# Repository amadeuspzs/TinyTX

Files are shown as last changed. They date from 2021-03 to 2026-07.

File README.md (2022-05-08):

# TinyTX

This repo picks up on the work on Nathan Chantrell, sadly R.I.P. late 2020.

* Nathan's website [via Archive.org](https://web.archive.org/web/20150202220320/http://nathan.chantrell.net/tinytx-wireless-sensor/)
* Nathan's [TinyTX repo on Github](https://github.com/nathanchantrell/TinyTX)
* Archive of [TinyTX3 hardware](TinyTX3/)

## Motivation

Since Nathan created TinyTX, both chips have evolved:

1. RFM12B -> [RFM69](https://www.hoperf.com/modules/rf_transceiver/index.html)
2. ATtiny84 -> ATtiny 0,1 series e.g. [ATtiny1614](https://ww1.microchip.com/downloads/en/DeviceDoc/ATtiny1614-16-17-DataSheet-DS40002204A.pdf)

## High level design

This project will create a TinyTX4 using:

1. RFM69HW
2. ATtiny1614
3. lowpowerlab's [RFM69](https://github.com/lowpowerlab/rfm69) library

And release all hardware and software in this repository.

## Radio module choice

Here is a comparison of [RFM69](https://www.hoperf.com/modules/rf_transceiver/index.html) variants:

Variant|Output (dBm)|Pinout|Size (mm)
---|---|---|---
RFM69[**W**](https://www.hoperf.com/modules/rf_transceiver/RFM69W.html)|13|RFM69W|19.7 x 16
RFM69[**CW**](https://www.hoperf.com/modules/rf_transceiver/RFM69C.html)|13|RFM69CW|16 x 16
RFM69[**HW**](https://www.hoperf.com/%20modules/rf_transceiver/RFM69HW.html)|20|RFM69W|19.7 x 16
RFM69[**HCW**](https://www.hoperf.com/modules/rf_transceiver/RFM69HCW.html)|20|RFM69HCW|16 x 16

i.e. RFM69W and RFM69HW share pinout, but are larger (19.7&nbsp;x&nbsp;16)mm vs the RFMCW and RFMHCW (16&nbsp;x&nbsp;16)mm.

For interoperability between normal and high-power modules, we'll go with the **RFM69(H)W** modules.

## Hardware versions

* [TinyTX4](hardware/TinyTX4) (monopole and SMA)

TinyTX4 Gif

## Software

See [software](software/) page.

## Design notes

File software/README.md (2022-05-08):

# TinyTX4 Software

* [Heartbeat (ping) sketch](ping/) - pings your gateway every ~5s
* [Heartbeat (ping-sleep) sketch](ping/) - pings your gateway every ~64s with sleep in between
* [Low power profiling](low-power-test/) - cycles 1s on and off with radio sleep to check power consumption
* [HC-SR04 Ultrasonic distance sensor](HC-SR04) - WIP water level sensor

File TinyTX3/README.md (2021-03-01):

# TinyTX3 Hardware

Archived from Nathan's website [via Archive.org](https://web.archive.org/web/20150202220320/http://nathan.chantrell.net/tinytx-wireless-sensor/):

## Schematic

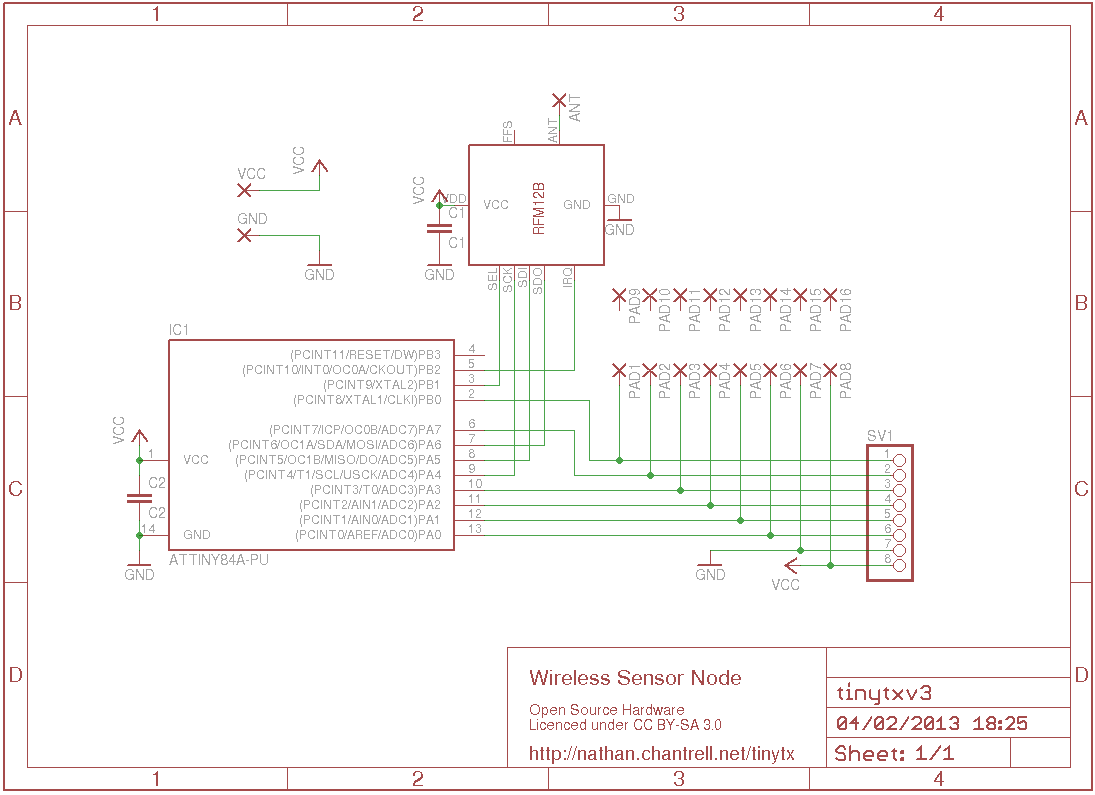
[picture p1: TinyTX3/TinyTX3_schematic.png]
Schematic


* [Eagle file](tinytx3.sch)
* [KiCad files](KiCad/)

## Board

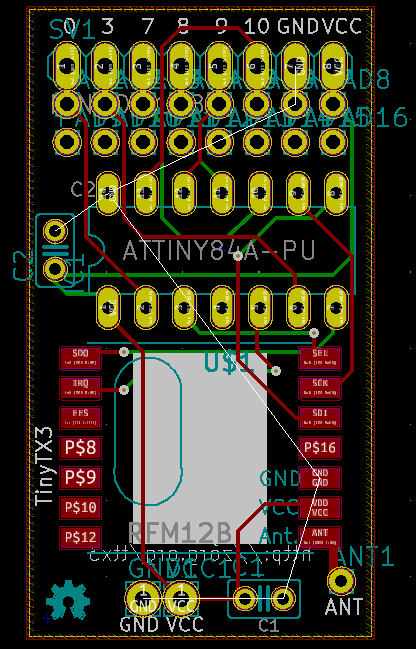
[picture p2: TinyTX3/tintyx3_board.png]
Board


* [Eagle file](tinytx3.brd)
* [KiCad files](KiCad/)

## Case

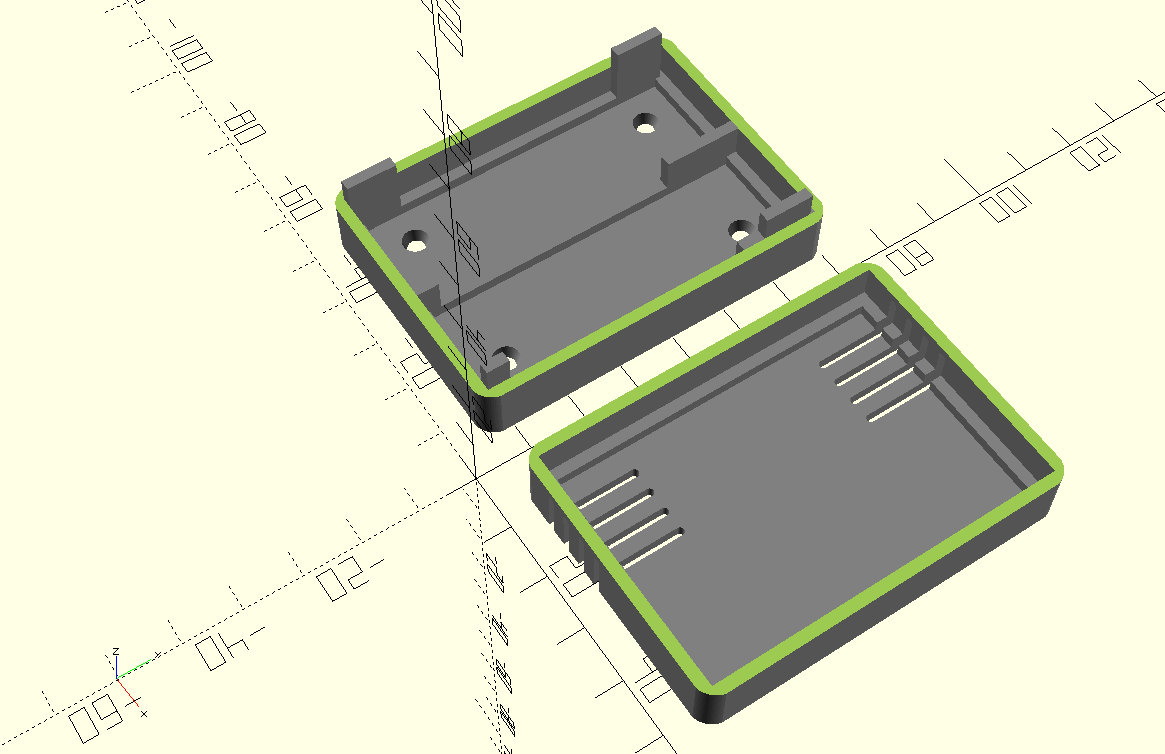
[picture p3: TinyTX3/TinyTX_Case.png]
Case


* [OpenSCAD](TinyTX_Case.scad)

## Implementation

### Pinout

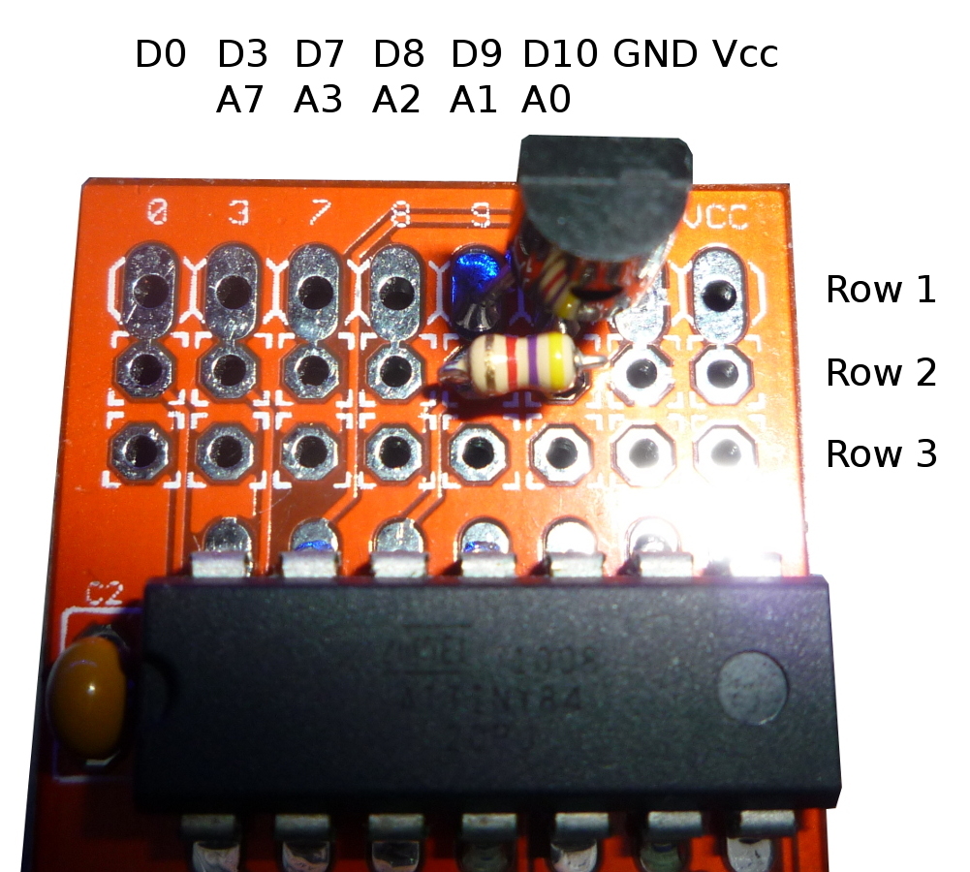
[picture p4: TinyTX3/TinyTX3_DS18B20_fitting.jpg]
Pinout


### AA implementation

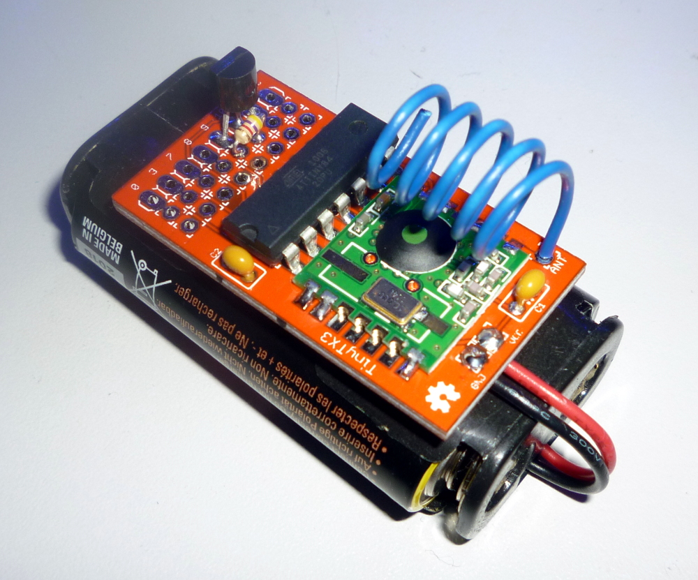
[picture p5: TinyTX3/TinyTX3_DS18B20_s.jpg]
AA implementation


### LiPo implementation

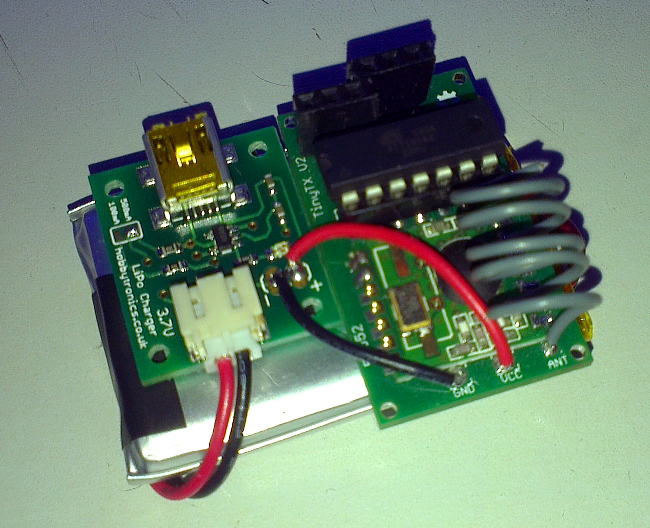
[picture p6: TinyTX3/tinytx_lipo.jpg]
LiPo implementation


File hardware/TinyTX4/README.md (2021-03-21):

# TinyTX4

Upgrades from TinyTX3:

* Updated to RFM69HW/W module
* Updated to ATtiny1614 SOIC
* Added optional [MCP1700](https://ww1.microchip.com/downloads/en/DeviceDoc/22049f.pdf)|[MCP1703](https://ww1.microchip.com/downloads/en/DeviceDoc/22049f.pdf) regulator for ~4-6V~ input ultra low dropout or ~4-16V input range (e.g. 9V battery, Lead Acid cells...). These can be bought in 3.3V or 5V out
* Added programming header with UPDI
* Labelled RX/TX ports for hardware UART
* Added ground planes to improved antenna performance
* Added optional SMA PCB for improved antenna performance

The monopole version keeps the same overall dimensions of TinyTX3.

## Monopole design

TinyTX4 schematic

TinyTX4 PCB front

TinyTX4 PCB rear

## SMA design

TinyTX4_sma PCB front

TinyTX4_sma PCB rear

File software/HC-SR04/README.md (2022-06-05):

# HC-SR04

Low power Ultrasonic range-finder:

1. CS-100 based HC-SR04 (3.3V)
2. NewPing with [modification to support ATTiny1614](https://bitbucket.org/teckel12/arduino-new-ping/pull-requests/8)
3. BSS84 MOSFET to switch on HC-SR04 (inverse), or power directly off GPIO

## Energy usage

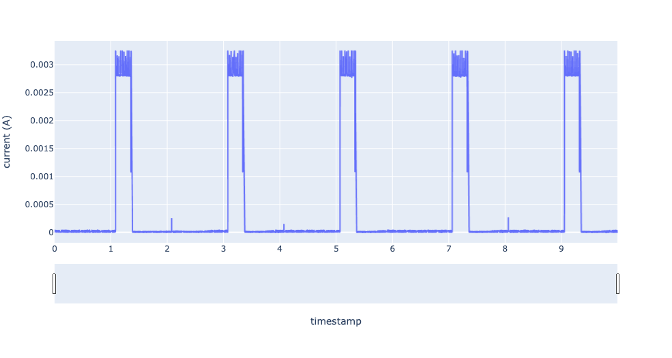
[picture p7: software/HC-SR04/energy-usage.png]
Energy usage diagram


* 20uA background =
* 3mA for ~150ms every 10 mins = 0.45mAs

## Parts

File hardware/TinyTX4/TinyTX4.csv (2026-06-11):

Reference | Qty | Value | DNP | Exclude from BOM | Exclude from Board | Footprint | Datasheet
AE1 | 1 | Antenna |  |  |  | Connector_Wire:SolderWirePad_1x01_Drill1mm | ~
BT1 | 1 | Battery |  |  |  | Connector_Wire:SolderWirePad_1x02_P3.81mm_Drill1mm | ~
C1,C2 | 2 | 0.1uF |  |  |  | Capacitor_SMD:C_1206_3216Metric_Pad1.42x1.75mm_HandSolder | ~
C3,C4 | 2 | 1uF |  |  |  | Capacitor_SMD:C_1206_3216Metric_Pad1.42x1.75mm_HandSolder | ~
J1 | 1 | Conn_01x03_Male |  |  |  | Connector_Wire:SolderWirePad_1x03_P3.175mm_Drill1mm | ~
J2 | 1 | Conn_01x08_Female |  |  |  | kicad-custom:SolderWirePadOval_1x08_Drill1mm | ~
J3,J4 | 2 | Conn_01x08_Female |  |  |  | kicad-custom:SolderWirePad_1x08_Drill1mm | ~
R1,R2 | 2 | R |  |  |  |  | ~
U1 | 1 | ATtiny1614-SS |  |  |  | Package_SO:SOIC-14_3.9x8.7mm_P1.27mm | http://ww1.microchip.com/downloads/en/DeviceDoc/ATtiny1614-data-sheet-40001995A.pdf
U2 | 1 | RFM69HW |  |  |  | RF_Module:HOPERF_RFM69HW | https://www.hoperf.com/data/upload/portal/20181127/5bfcbb56f1fd7.pdf
U3 | 1 | MCP1703A-3302_SOT23 |  |  |  | Package_TO_SOT_SMD:SOT-23 | http://ww1.microchip.com/downloads/en/DeviceDoc/20005122B.pdf

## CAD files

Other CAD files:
TinyTX3/TinyTX_Case.scad

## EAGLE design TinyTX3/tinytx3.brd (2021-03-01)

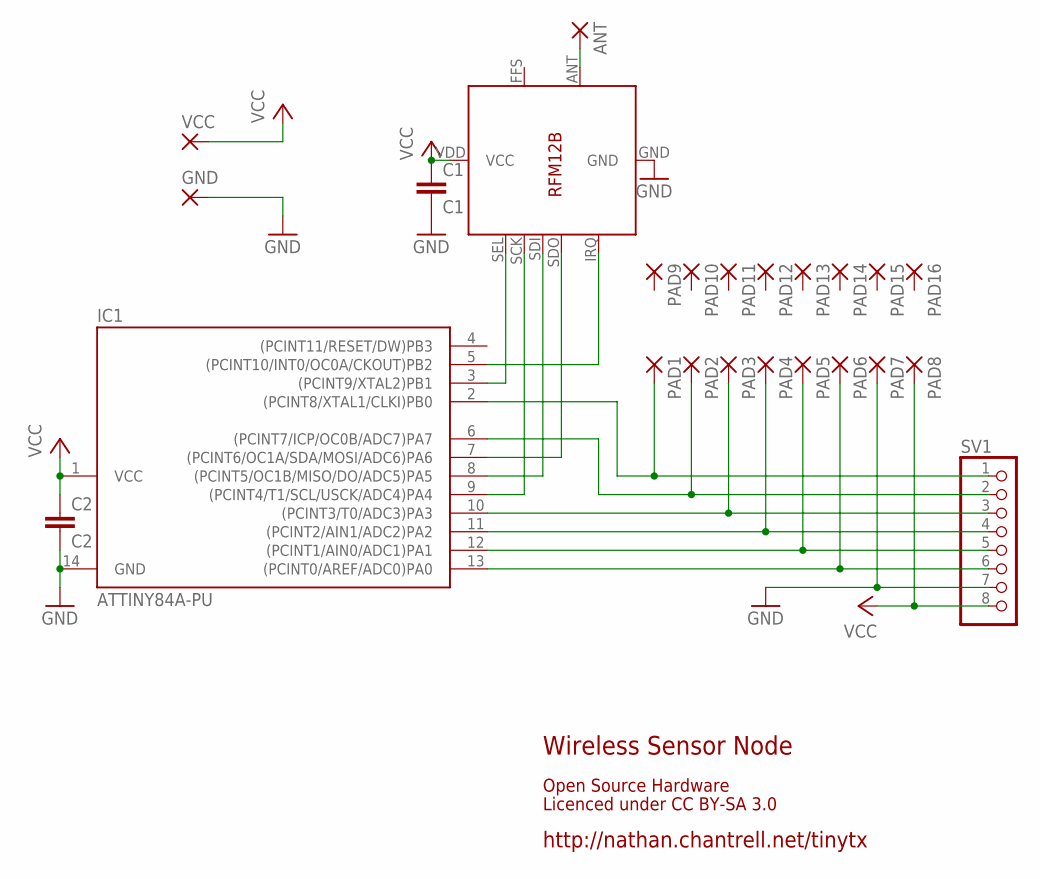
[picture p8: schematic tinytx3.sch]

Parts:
ANT: 1,6/0,8
C1: C1; C025-025X050
C2: C2; C025-025X050
GND: 2,15/1,0
IC1: ATTINY84A-PU; DIL14
PAD1, PAD2, PAD3, PAD4, PAD5, PAD6, PAD7, PAD8, PAD9, PAD10, PAD11, PAD12, PAD13, PAD14, PAD15, PAD16: 1,6/0,9
SV1: PINHD-1X8; 1X08
U$1: RFM12B
VCC: 2,15/1,0

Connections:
GND: C1.2, C2.2, GND.1, IC1.14 (GND), PAD7.1, SV1.7, U$1.GND
unnamed: IC1.3 ((PCINT9/XTAL2)PB1), U$1.SEL
unnamed: IC1.5 ((PCINT10/INT0/OC0A/CKOUT)PB2), U$1.IRQ
unnamed: IC1.8 ((PCINT5/OC1B/MISO/DO/ADC5)PA5), U$1.SDI
unnamed: IC1.7 ((PCINT6/OC1A/SDA/MOSI/ADC6)PA6), U$1.SDO
unnamed: ANT.1, U$1.ANT
unnamed: IC1.9 ((PCINT4/T1/SCL/USCK/ADC4)PA4), U$1.SCK
unnamed: IC1.6 ((PCINT7/ICP/OC0B/ADC7)PA7), PAD2.1, SV1.2
unnamed: IC1.13 ((PCINT0/AREF/ADC0)PA0), PAD6.1, SV1.6
unnamed: IC1.12 ((PCINT1/AIN0/ADC1)PA1), PAD5.1, SV1.5
unnamed: IC1.2 ((PCINT8/XTAL1/CLKI)PB0), PAD1.1, SV1.1
unnamed: IC1.11 ((PCINT2/AIN1/ADC2)PA2), PAD4.1, SV1.4
unnamed: IC1.10 ((PCINT3/T0/ADC3)PA3), PAD3.1, SV1.3
VCC: C1.1, C2.1, IC1.1 (VCC), PAD8.1, SV1.8, U$1.VDD (VCC), VCC.1

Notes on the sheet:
http://nathan.chantrell.net/tinytx
Wireless Sensor Node
Licenced under CC BY-SA 3.0
Open Source Hardware

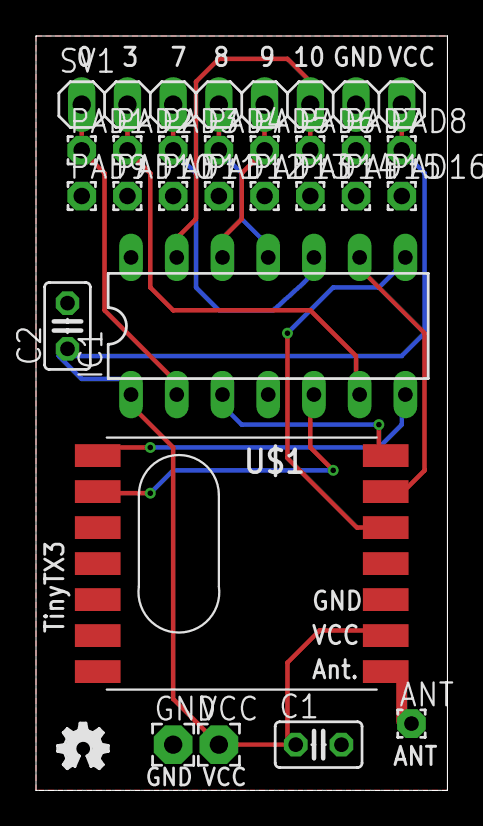
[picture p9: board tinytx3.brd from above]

Board: 2 copper layers, 22.9 x 41.9 mm, 25 parts (0 on the bottom side), 14 nets.

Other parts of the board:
U$2: OSHW_FILLX100_NOTEXT

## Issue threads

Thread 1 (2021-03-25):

TinyTX4

amadeuspzs, 2021-03-25:
- [ ] Pin spacing on UPDI header is not standard
- [ ] RX/TX are wrong way around on silk screen layer

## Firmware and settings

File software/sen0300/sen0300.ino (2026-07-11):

/*
  SEN0300 Integration

  Reads distance and temperature from DFRobot SEN0300 Waterproof Ultrasonic Sensor
  and transmits data via RFM69.

  Wiring Connections:
  TinyTX Header L-R:
  7 6 5 4 1 3 3V3 GND

  ------------------------------------
  Sensor Pin   | TinyTX Pin (Arduino Pin)
  ------------------------------------
  VCC          | VCC
  GND          | GND
  RX (Trigger) | Pin 1 (PA5)
  TX (Data)    | Pin 3 (PA7)
  ------------------------------------

  Pin 4 (PB3) is the MOSFET gate to power the sensor on/off (active LOW).
  Pin 5 (PB2) is Hardware Serial TX — debug output when DEBUG is defined in config.h.
  Pin 6 (PB1) is the dummy SoftwareSerial TX (sensor serial never transmits).
  Pin 7 (PB0) is used for voltage divider battery voltage sensor input (ADC).

  Sleep:
    RTC PIT wakes the MCU every ~1 s; TARGET_SLEEPS ticks pass before the
    next measurement, giving a variable transmit interval without busy-delay.
*/

#include <avr/sleep.h>
#include <SoftwareSerial.h>
#include <SPI.h>
#include "config.h"
#include <math.h>

// ---------------------------------------------------------------------------
// Radio
// ---------------------------------------------------------------------------
#ifdef ENABLE_ATC
RFM69_ATC radio;
#else
RFM69 radio;
#endif

// ---------------------------------------------------------------------------
// SoftwareSerial for sensor receive (TX pin is dummy, never driven)
// ---------------------------------------------------------------------------
SoftwareSerial sensorSerial(RX_PIN, DUMMY_TX_PIN);

// ---------------------------------------------------------------------------
// Radio retries
// ---------------------------------------------------------------------------
int numRetries = 3;
int timeout = 50;      // ms to wait for ACK
bool heartbeat = true; // binary heartbeat every sleep cycle

// ---------------------------------------------------------------------------
// Payload
// ---------------------------------------------------------------------------
Payload theData;

// ---------------------------------------------------------------------------
// Sleep / RTC state
// ---------------------------------------------------------------------------
volatile int current_sleeps = 0; // incremented by the PIT ISR

// ---------------------------------------------------------------------------
// RTC / PIT initialisation
// One PIT interrupt every ~1 s (CYC1024 @ 1.024 kHz internal oscillator)
// ---------------------------------------------------------------------------
void RTC_init(void)
{
  RTC.CLKSEL = RTC_CLKSEL_INT1K_gc; // 1.024 kHz ULP oscillator
  while (RTC.STATUS > 0 || RTC.PITSTATUS)
    ;                                  // wait for sync
  RTC.PITINTCTRL = RTC_PI_bm;          // enable PIT interrupt
  RTC.PITCTRLA = RTC_PERIOD_CYC1024_gc // ~1 s per tick
                 | RTC_PITEN_bm;
  // enable PIT
}

ISR(RTC_PIT_vect)
{
  current_sleeps++;
  RTC.PITINTFLAGS = RTC_PI_bm; // clear flag (write 1 to clear)
}

// ---------------------------------------------------------------------------
// Forward declarations
// ---------------------------------------------------------------------------
bool readSensorData(float &distance_cm, float &temperature_c);

// ---------------------------------------------------------------------------
// setup()
// ---------------------------------------------------------------------------
void setup()
{

  // 1. Hold TRIG_PIN HIGH immediately to prevent sensor entering Switch Mode
  pinMode(TRIG_PIN, OUTPUT);
  digitalWrite(TRIG_PIN, HIGH);

  // 2. Battery voltage sensor pin
  analogReference(VDD); // 3V3
  pinMode(BATTERY_SENSOR_PIN, INPUT);

  // 3. Debug serial (hardware Serial on PB2)
  DBG_BEGIN(SERIAL_BAUD);
#ifdef DEBUG
  // Disable the hardware UART receiver to release PB3 back to normal GPIO
  USART0.CTRLB &= ~USART_RXEN_bm;
#endif
  delay(100);
  DBG_PRINTLN("\n\n=== TinyTX SEN0300 Starting ===");

  // 4. Power off the sensor via MOSFET (active LOW gate logic)
  pinMode(POWER_PIN, OUTPUT);
  digitalWrite(POWER_PIN, LOW); // power off sensor

  // 5. Sensor serial (SoftwareSerial on PA7)
  sensorSerial.begin(9600);

  // 6. Radio
  radio.initialize(FREQUENCY, NODEID, NETWORKID);
  radio.setFrequency(433000000); // lock to exactly 433.0 MHz

#ifdef IS_RFM69HW_HCW
  radio.setHighPower();
#endif
#ifdef ENABLE_ATC
  radio.enableAutoPower(ATC_RSSI);
#endif

#ifdef DEBUG
  // 6. Verify radio frequency via register readback
  uint32_t frf = ((uint32_t)radio.readReg(0x07) << 16) |
                 ((uint32_t)radio.readReg(0x08) << 8) |
                 radio.readReg(0x09);
  float freq_mhz = (frf * 61.03515625f) / 1000000.0f;
#endif
  DBG_PRINT("Radio frequency: ");
  DBG_PRINT2(freq_mhz, 2);
  DBG_PRINTLN(" MHz");

  DBG_PRINTLN("Setup complete. Starting loop...\n");

  // 7. RTC PIT sleep setup
  RTC_init();
  set_sleep_mode(SLEEP_MODE_PWR_DOWN);
  sleep_enable();
  sei();
}

// ---------------------------------------------------------------------------
// loop()
// ---------------------------------------------------------------------------
void loop()
{
  // Fire on first wake (current_sleeps == 0) or once TARGET_SLEEPS ticks have passed
  if (current_sleeps == 0 || current_sleeps >= TARGET_SLEEPS)
  {
    DBG_PRINT("Heartbeat = ");
    DBG_PRINTLN(heartbeat);
    DBG_PRINTLN("--- Measuring Battery ADC ratio ---");
    float adcRatio = readBatteryRatio();
    theData.adcRatio = adcRatio;
    DBG_PRINT("Battery ADC ratio = ");
    DBG_PRINTLN(adcRatio);
    DBG_PRINTLN("--- Triggering Sensor Measurement ---");
    // digitalWrite(POWER_PIN, LOW); // power on sensor
    delay(100); // wait for sensor to power up and stabilise
    float dist = 0.0f;
    float temp = 0.0f;

    theData.heartbeat = heartbeat;

    if (readSensorData(dist, temp))
    {
      theData.distance_cm = dist;
      theData.temperature_c = temp;

      DBG_PRINT("Distance = ");
      DBG_PRINT2(theData.distance_cm, 1);
      DBG_PRINT(" cm, Temperature = ");
      DBG_PRINT2(theData.temperature_c, 1);
      DBG_PRINTLN(" C");
    }
    else
    {
      DBG_PRINTLN("Failed to read sensor data.");
      theData.distance_cm = NAN; // indicate invalid reading
      theData.temperature_c = NAN;
    }

    DBG_PRINT("Sending via RFM69... ");

    if (radio.sendWithRetry(GATEWAYID, (const void *)(&theData), sizeof(theData), numRetries, timeout))
    {
      DBG_PRINTLN("ACK received!");
    }
    else
    {
      DBG_PRINTLN("no response.");
    }
    current_sleeps = 0; // reset sleep counter

    DBG_PRINT("Sleeping for ~");
    DBG_PRINT(TARGET_SLEEPS);
    DBG_PRINTLN(" seconds...\n");
#ifdef DEBUG
    Serial.flush();
#endif
    heartbeat = !heartbeat; // toggle heartbeat for next sleep cycle
    // digitalWrite(POWER_PIN, HIGH); // power off sensor before sleeping
  } // end wake up logic

  radio.sleep(); // put radio to sleep before CPU sleeps
  sleep_cpu();   // sleep until next PIT interrupt (~1 s), then loop() reruns
}

float readBatteryRatio()
{
  // Discard the first reading
  analogRead(BATTERY_SENSOR_PIN);

  uint32_t adcAccumulator = 0;
  const int samples = 4;

  for (int i = 0; i < samples; i++)
  {
    adcAccumulator += analogRead(BATTERY_SENSOR_PIN);
  }

  float adcAverage = (float)adcAccumulator / samples;

  return adcAverage / 1023.0;
}

// ---------------------------------------------------------------------------
// readSensorData()
// Triggers the SEN0300, reads and validates the 6-byte frame, returns
// distance (cm) and temperature (°C).
// ---------------------------------------------------------------------------
bool readSensorData(float &distance_cm, float &temperature_c)
{
  // Flush stale bytes
  while (sensorSerial.available())
    sensorSerial.read();

  // Active-LOW trigger pulse (10 ms, within the 0.1–10 ms spec)
  digitalWrite(TRIG_PIN, LOW);
  delay(10);
  digitalWrite(TRIG_PIN, HIGH);

  unsigned char buffer_RTT[6] = {0};
  int bytesRead = 0;
  unsigned long startTime = millis();
  bool foundHeader = false;

  // 1. Align on header byte 0xFF
  while (millis() - startTime < 300)
  {
    if (sensorSerial.available() > 0)
    {
      byte b = sensorSerial.read();
      if (b == 0xFF)
      {
        buffer_RTT[0] = 0xFF;
        foundHeader = true;
        break;
      }
    }
  }

  if (!foundHeader)
  {
    DBG_PRINTLN("  [Error] Timeout: Header byte (0xFF) not found.");
    return false;
  }

  // 2. Read remaining 5 bytes
  bytesRead = 1;
  while (bytesRead < 6 && (millis() - startTime < 500))
  {
    if (sensorSerial.available() > 0)
      buffer_RTT[bytesRead++] = sensorSerial.read();
  }

  if (bytesRead < 6)
  {
    DBG_PRINT("  [Error] Incomplete frame (");
    DBG_PRINT(bytesRead);
    DBG_PRINTLN("/6 bytes).");
    return false;
  }

  // 3. Print raw frame for debugging
  DBG_PRINT("  [Raw RX] ");
  for (int i = 0; i < 6; i++)
  {
    DBG_PRINT("0x");
    if (buffer_RTT[i] < 0x10)
      DBG_PRINT("0");
    DBG_PRINT2(buffer_RTT[i], HEX);
    DBG_PRINT(" ");
  }
  DBG_PRINTLN("");

  // 4. Verify checksum: SUM = (byte0..4) & 0xFF
  byte expected = (buffer_RTT[0] + buffer_RTT[1] + buffer_RTT[2] +
                   buffer_RTT[3] + buffer_RTT[4]) &
                  0xFF;
  if (buffer_RTT[5] != expected)
  {
    DBG_PRINT("  [Error] Checksum mismatch. Expected 0x");
    DBG_PRINT2(expected, HEX);
    DBG_PRINT(", got 0x");
    DBG_PRINT2(buffer_RTT[5], HEX);
    DBG_PRINTLN("");
    return false;
  }

  // 5. Parse distance (bytes 1–2, in mm)
  int range_mm = (buffer_RTT[1] << 8) | buffer_RTT[2];

  // 6. Parse temperature (bytes 3–4; MSB of byte 3 = sign bit)
  bool isNegative = (buffer_RTT[3] & 0x80) != 0;
  int tempVal = ((buffer_RTT[3] & 0x7F) << 8) | buffer_RTT[4];
  float temp = tempVal / 10.0f;
  if (isNegative)
    temp = -temp;

  distance_cm = range_mm / 10.0f;
  temperature_c = temp;

  return true;
}

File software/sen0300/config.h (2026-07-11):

#ifndef CONFIG_H
#define CONFIG_H

#include <RFM69.h>
#include <RFM69_ATC.h>

// ---------------------------------------------------------------------------
// Debug output via Hardware Serial (TX on PB2, ATtiny1614 default)
// Comment out #define DEBUG to disable all debug output for production
// (saves flash, RAM, and avoids Serial init overhead)
// ---------------------------------------------------------------------------
// #define DEBUG

#ifdef DEBUG
#define DBG_BEGIN(baud) Serial.begin(baud)
#define DBG_PRINT(x) Serial.print(x)
#define DBG_PRINTLN(x) Serial.println(x)
#define DBG_PRINT2(x, f) Serial.print(x, f)
#else
#define DBG_BEGIN(baud)
#define DBG_PRINT(x)
#define DBG_PRINTLN(x)
#define DBG_PRINT2(x, f)
#endif

#define SERIAL_BAUD 9600

// ---------------------------------------------------------------------------
// Radio Configuration
// ---------------------------------------------------------------------------
#define NODEID 3    // ID of this device
#define NETWORKID 1 // Your network ID
#define GATEWAYID 1 // ID of your gateway
#define FREQUENCY RF69_433MHZ
#define IS_RFM69HW_HCW // Uncomment only for RFM69HW/HCW!
#define ENABLE_ATC     // Comment out to disable Auto Transmission Control
#define ATC_RSSI -75   // Target RSSI (dBm)

// ---------------------------------------------------------------------------
// Pin Configuration
// ---------------------------------------------------------------------------
#define TRIG_PIN PIN_PA5           // Pin 1 (PA5) trigger sensor measurement (active low pulse)
#define RX_PIN PIN_PA7             // Pin 3 (PA7) SoftwareSerial RX from sensor
#define DUMMY_TX_PIN PIN_PB1       // Pin 6 (PB1) unused/dummy SoftwareSerial TX
#define POWER_PIN PIN_PB3          // Pin 4 (PB3) MOSFET gate to power sensor on/off
#define BATTERY_SENSOR_PIN PIN_PB0 // Pin 7 (PB0) ADC input for battery voltage measurement
// Note: PB2 is Hardware Serial TX (debug output when DEBUG is defined)

// ---------------------------------------------------------------------------
// Sleep / Timing Configuration
//
// The RTC PIT fires every ~1 second (RTC_PERIOD_CYC1024_gc @ 1.024 kHz).
// Total sleep time ≈ TARGET_SLEEPS seconds.
// Set to 5 for bench testing; change to e.g. 300 for ~5 min in production.
// ---------------------------------------------------------------------------
#define TARGET_SLEEPS 1800 // 30 mins

// ---------------------------------------------------------------------------
// Radio Class Selection
// ---------------------------------------------------------------------------
#ifdef ENABLE_ATC
extern RFM69_ATC radio;
#else
extern RFM69 radio;
#endif

// ---------------------------------------------------------------------------
// Payload structure transmitted over RFM69
// ---------------------------------------------------------------------------
typedef struct
{
  float distance_cm;
  float temperature_c;
  float adcRatio;
  bool heartbeat;
} Payload;

#endif // CONFIG_H

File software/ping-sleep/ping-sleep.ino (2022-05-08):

/*

  Test sketch to get your TinyTX up and running.

  You will need a receiver (gateway) set up to receive packets.

  e.g. https://github.com/amadeuspzs/rfm69-pi-avr/tree/master/hub-pi

  Packets will be toggled between 0 and 1 every 5 seconds, providing a ping

  LED will blink once for transmit, and flash for received ACK

*/

#include <avr/sleep.h>
#include <RFM69.h>      // https://github.com/lowpowerlab/rfm69
#include <RFM69_ATC.h>  // https://github.com/lowpowerlab/rfm69
#include <SPI.h>

#define debug false     // enable Serial output
#define led 7           // positive lead of LED aka PB0
#define NODEID      2   // id of this device
#define NETWORKID   1   // your network id
#define GATEWAYID   1   // id of your gateway
#define FREQUENCY     RF69_433MHZ
//#define ENCRYPTKEY    "sampleEncryptKey" //has to be same 16 characters/bytes on all nodes, not more not less!
#define IS_RFM69HW_HCW  //uncomment only for RFM69HW/HCW! Leave out if you have RFM69W/CW! See https://lowpowerlab.com/guide/moteino/transceivers/
// #define ENABLE_ATC    //comment out this line to disable AUTO TRANSMISSION CONTROL
// #define ATC_RSSI      -80 // target RSSI (dBm)
#define SERIAL_BAUD 9600

#ifdef ENABLE_ATC
  RFM69_ATC radio;
#else
  RFM69 radio;
#endif

int numRetries = 3; // default is 2
int timeout = 50; // ms to wait for ACK, default is 30

volatile int current_sleeps = 0;        // counter for how many times PIT has woken up
int target_sleeps = 2;                  // target for total sleep time. Increment of the RTC_PERIOD setting below
                                        // e.g. RTC_PERIOD_CYC32768_gc = 32s, target_sleeps = 2 -> 64s sleep

typedef struct {
  bool state;
} Payload;
Payload theData;


// setup for the RTC
void RTC_init(void) {
  // initialise RTC:
  RTC.CLKSEL = RTC_CLKSEL_INT1K_gc;         // 1.024kHz Internal Ultra-Low-Power Oscillator (from OSCULP32K)
  while (RTC.STATUS > 0 || RTC.PITSTATUS);  // Wait for all registers to be synchronised
  RTC.PITINTCTRL = RTC_PI_bm;               // PIT Interrupt: enabled
  RTC.PITCTRLA = RTC_PERIOD_CYC4096_gc      // Num cycles between interrupt. RTC Clock Cycles 1024, resulting in 1024/1024Hz = every 1 seconds
  | RTC_PITEN_bm;                           // enable PIT counter
}

// interrupt subroutine, runs when PIT wakes up
ISR(RTC_PIT_vect) {
  current_sleeps += 1;                  // increment sleep counter
  RTC.PITINTFLAGS = RTC_PI_bm;          // clear interrupt flag by writing '1' (required)
}

void setup() {
  // switch off unneeded pins for power saving
  pinMode(PIN_PA5, INPUT_PULLUP);
  pinMode(PIN_PA7, INPUT_PULLUP);
  pinMode(PIN_PB1, INPUT_PULLUP);
  pinMode(PIN_PB2, INPUT_PULLUP);
  pinMode(PIN_PB3, INPUT_PULLUP);

  if (debug) Serial.begin(SERIAL_BAUD);
  radio.initialize(FREQUENCY,NODEID,NETWORKID);
  #ifdef IS_RFM69HW_HCW
    radio.setHighPower(); //must include this only for RFM69HW/HCW!
  #endif
  #ifdef ENABLE_ATC
    radio.enableAutoPower(ATC_RSSI); // set the target RSSI
  #endif
  #ifdef ENCRYPTKEY
    radio.encrypt(ENCRYPTKEY);
  #endif
  if (debug) Serial.print("Transmitting at ");
  if (debug) Serial.print(FREQUENCY==RF69_433MHZ ? 433 : FREQUENCY==RF69_868MHZ ? 868 : 915);
  if (debug) Serial.println(" MHz");

  pinMode(led, OUTPUT);   // blinker
  digitalWrite(led, LOW); // turn off

  RTC_init();                           // initialise the RTC timer
  set_sleep_mode(SLEEP_MODE_PWR_DOWN);  // set sleep mode to POWER DOWN mode
  sleep_enable();                       // enable sleep mode, but not going to sleep yet
  sei();                                // enable interrupts

}

void blink(int times = 1, int interval = 100) {
  for (int n=0; n < times; n++) {
    digitalWrite(led, HIGH);
    delay(interval);
    digitalWrite(led, LOW);
    delay(interval);
  }
}


void loop() {
  if (current_sleeps == 0 || current_sleeps == target_sleeps ) { // just switched on, or we've hit our target
    // toggle state
    theData.state = (theData.state == 0) ? 1 : 0;

    if (debug) Serial.print("Sending struct (");
    if (debug) Serial.print(sizeof(theData));
    if (debug) Serial.print(" bytes): ");
    if (debug) Serial.print(theData.state);
    if (debug) Serial.print(" ... ");

    blink(); // blink to trasmit

    delay(100); // delay to allow for easier power measurement

    if (radio.sendWithRetry(GATEWAYID, (const void*)(&theData), sizeof(theData), numRetries, timeout)) {
      if (debug) Serial.print(" ok!");
      delay(100);
      blink(5, 30); // flash to show ACK
    } else {
      if (debug) Serial.print(" nothing...");
    }

    if (debug) Serial.println();

    current_sleeps = 0;                           // reset sleep counter to 0

  }
  radio.sleep();    // sleep radio
  sleep_cpu();                          /* Sleep the device and wait for an interrupt to continue */

}

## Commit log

2021-03-01 Add TinyTX3 hardware
    [TinyTX_Case.scad, tinytx3.brd, tinytx3.kicad_pcb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]
2021-03-09 Remove kicad collateral
2021-03-09 Add 3d graphic
    [TinyTX4.kicad_pcb]
2022-04-03 Add printed version
    [TinyTX4-sma.kicad_pcb, TinyTX4-sma.sch, TinyTX4.kicad_pcb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]
2022-04-03 Add latest version
    [TinyTX4-sma-B_Cu.gbr, TinyTX4-sma-B_Mask.gbr, TinyTX4-sma-B_SilkS.gbr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]
2022-05-08 fix: revert to 1s on 1s off
    [low-power-test.ino]
2022-06-06 fix: rename sketch file
    [HC-SR04.ino]
2026-06-11 feat: updated to latest
    [TinyTX4.csv]
2026-06-21 wip: sen0300 low power with heartbeat
2026-07-11 feat: battery sensor
